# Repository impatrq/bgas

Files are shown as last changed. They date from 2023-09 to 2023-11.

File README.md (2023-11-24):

# BGas
Repositorio del proyecto BGas

## Integrantes:
- Britez, Franco  [codeSTACKr | LinkedIn][linkedinbr]

- Caceres, Luca  [codeSTACKr | LinkedIn][linkedinca]

- Chioli, Lautaro  [codeSTACKr | LinkedIn][linkedinch]

- Daglio, Santiago  [codeSTACKr | LinkedIn][linkedinda]

- Ferman, Joaquin  [codeSTACKr | LinkedIn][linkedinfe]

- Grochovski, Victor  [codeSTACKr | LinkedIn][linkedingr]

- Rossetti, Gonzalo  [codeSTACKr | LinkedIn][linkedinro] <br><br/>
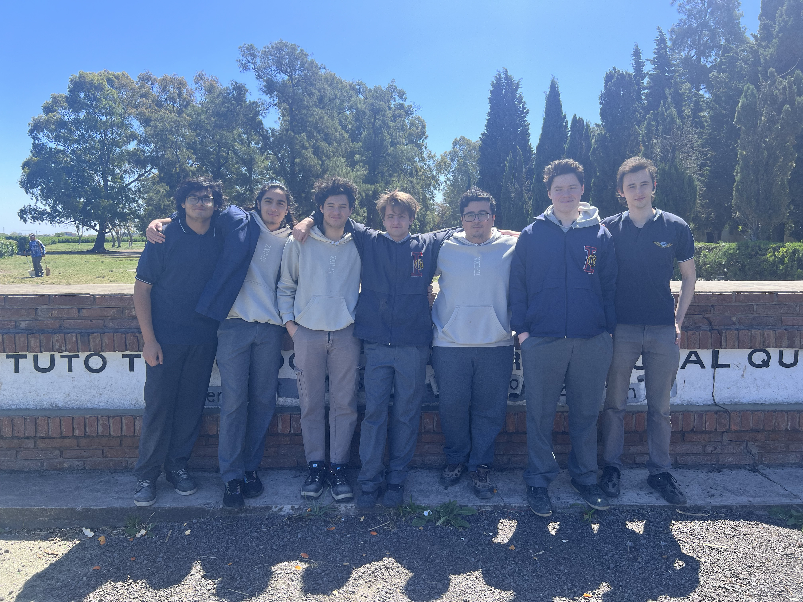
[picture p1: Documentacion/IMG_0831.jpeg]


## Objetivo:
BGas es un sistema compuesto por un generador de biogas y un subsistema electronico de monitoreo para leer los parametros en tiempo real del proceso mencionado, y asi tener una generacion de energia mas facil y segura.

## ¿Que es el biogas?
El biogas es un gas natural producido por la descomposicion anaerobica de materia organica. Este gas esta compuesto entre un 60% y 70% de metano, siendo el resto principalmente dioxido de carbono. El biogas y el biometano (que se obtiene luego de que el biogas pase por un proceso de filtrado para que solo quede el metano) son las dos formas de bioenergia de mas rapido crecimiento a nivel mundial y se espera que tengan un rol clave en la transicion hacia un mundo mas sostenible.

## Funcionamiento 
Los residuos organicos deben ser colocados en el recipiente de biogas donde se someterán a un proceso de descomposicion anaerobica. Se podrá ver el proceso de produccion de biogas mediante un LCD 16x2 controlado por tres botones, o a traves de una aplicacion para telefonos celulares. Al final del proceso, el usuario obtendrá biogas y biofertilizante.  

## ¿Donde utilizarlo?
Si bien a un biodigestor se le puede sacar el maximo provecho en un establecimiento agropecuario o agroindustrial, incluso una casa en un area urbana puede crear una cantidad considerable de biogas. Nuestro sistema apunta a que cualquier establecimiento (ya sea rural o urbano) pueda generar energia de la forma mas eficiente posible. 

## Files tree

- main
  - App
    - android.txt
    - bin
    - buildozer.spec
    - main.kv
    - main.py
  - Documentacion
    - Carpetas
    - Certificados
    - Banner
    - Presentacion
    - BOM (Bill Of Material)
    - Manual de usuario
  - Electronica
    - Circuitos
    - PCBs
  - Estructura
    - Visuales de la estructura
  - Modelos
    - Modelos de blender
  - Programa principal
    - main.py
    - librerias
  - Web
    - CNAME
    - CSS
    - index.html
    - JS
  - Imagenes
    - Stickers
    - Logo

## Seguinos en nuestras redes:
[codeSTACKr | Instagram][instagram]
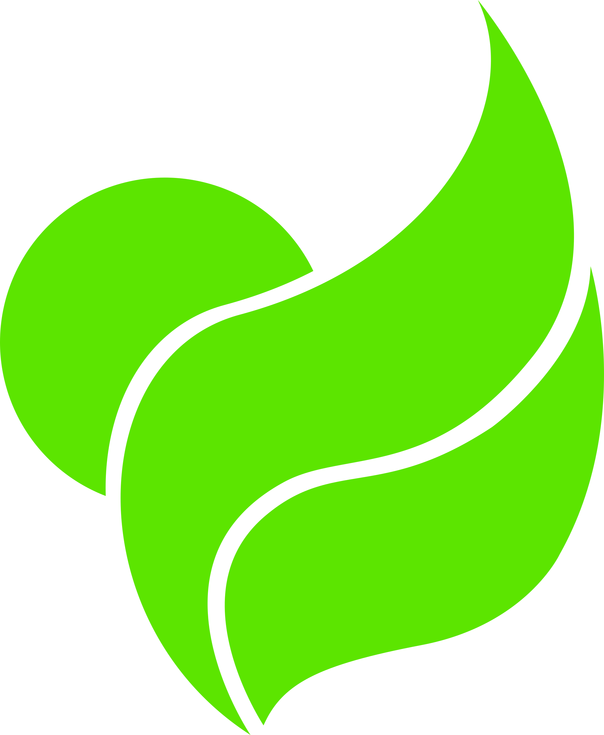
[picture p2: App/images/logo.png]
[][bgas]
[codeSTACKr | LinkedIn][linkedin]

[instagram]: https://instagram.com/proyecto.bgas?igshid=NGVhN2U2NjQ0Yg==
[bgas]: https://bgas.ar/
[Linkedin]: https://www.linkedin.com/company/101246268
[linkedinbr]: https://www.linkedin.com/in/franco-britez-b33523277/
[linkedinca]: https://www.linkedin.com/in/luca-c%C3%A1ceres-996389281/
[linkedinch]: https://www.linkedin.com/in/lautaro-chioli-87a68a27a/
[linkedinda]: https://www.linkedin.com/in/santiago-daglio-96b716295/
[linkedinfe]: https://www.linkedin.com/in/joaquin-ferman-b8b843259/
[linkedingr]: https://www.linkedin.com/in/victorgrochovski/
[linkedinro]: https://www.linkedin.com/in/gonzalo-rossetti-146219288/

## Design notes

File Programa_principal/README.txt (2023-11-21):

Carpeta para la programacion del micro.

Main.py ---->   Codigo principal del ESP32 transmisor

librerias:

LCD:       -lcd.api.py
           -i2c.lcd.py

MQ2:       -MQ2-py
           -BaseMQ.py

DS18B20:   -ds18x20.py
           -onewire.py

Otros:     -pyRTOS.py

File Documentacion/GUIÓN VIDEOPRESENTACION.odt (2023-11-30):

Bgas es un biodigestor inteligente, esta analizado por 3 sensores: mq2 sensor de gas, mpx5999d sensor de presión, ds18d20 sensor de temperatura. Esto es especialmente útil para los campos, dado la cantidad de abono que se puede usar para el biodigestor, además de las complicaciones que puede presentar para alguien que vive en el campo, considerando también las dificultades para obtener gas y lo costoso que puede resultar.

Al momento en que llega tu bgas, cargas el biodigestor con el mismo volumen de agua y materia orgánica; el volumen total puede ser de máximo 4/5 del balde (2/5 de agua y 2/5 de materia orgánica). En un plazo de 14 días, inicia la producción de tu propio gas.

La materia orgánica estará generando gas durante 4 meses; después de ese período, es necesario cambiar el contenido. La cantidad de gas generado dependerá del tipo de materia que pongas en el bgas.

Es necesario comprar otro biodigestor si el primero está dañado. Los materiales utilizados para un bgas están compuestos de plástico y metal. Sin embargo, si se trata de forma adecuada, el biodigestor puede durar toda tu vida.

El gas generado puede ser utilizado para cocina, calefacción y cualquier necesidad hogareña. Si tienes una buena cantidad de gas generado mensualmente, no será necesario volver a pagar por el servicio de gas.

El biodigestor es alimentado por energía solar, ya que no se necesita mucha energía para que todo funcione con normalidad.

Existen dos formas de revisar la información del biodigestor: puedes verla en la pantalla que se encuentra en el mismo, y también puedes descargar nuestra aplicación que proporciona esa información e informa del pico de eficiencia del biogás y cuánto tiempo durará dicho pico de eficiencia.

La application se comunica con el biodigestor atrabes de una antena de cumunicacion por internet llamada LORA

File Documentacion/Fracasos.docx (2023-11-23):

Fracasos

LoRa:

Documentación Usada:

https://github.com/rpsreal/pySX127x/blob/master/

Una de las librerías con las que más lejos llegue, no hubo problemas de compatibilidad con el micro usado, tampoco con el lenguaje, pero cuando intente usar el código de prueba con la librería ofrecida, me daba errores relacionados a la propia librería, y al estar relacionados a protocolos I2C, tema en el cual no estoy tan capacitado como para solucionar algo así, pase a la siguiente (Aunque en retrospectiva era la que tenia más chance de funcionar).

https://www.instructables.com/Arduino-LoRa-ESP32-LoRa-Gateway-Obtain-Remote-Ardu/

Confundido al principio por la diferencia, este ofrece un codigo para un módulo LoRaWAN, muy similar pero igualmente tuve problemas al momento de declarar los pines de mi módulo comparados con el del “tutorial”.

https://github.com/lemariva/uPyLoRaWAN/blob/master/main.py

Con diferencia con el que más lejos llegué, resolví algunos problemas (por ejemplo bypasee una autenticación de versión de python atrasada), pero al momento de hacerlo andar, lo cual ocurrió sin problemas, simplemente no hizo nada. Más específicamente el ESP encargado de enviar información informaba hacerlo, el encargado de recibirla lo mismo, pero algo en el medio no andaba. Dada la naturaleza del problema, que iba de la mano de un error en la comunicación (I2C) y no uno de lógica, decidí pasar a la siguiente librería.

https://www.arduino.cc/reference/en/libraries/lora/

Adicionalmente, intente usar una librería de arduino (lenguaje del cual es nativo el módulo) aunque no tuve disponible un módulo arduino a la mano en el poco tiempo hasta que un accidente rompió la antena de uno de los módulos, así incapacitando mis posibilidades de probar la comunicación aunque sea de esta forma tan precaria.

https://lemariva.com/blog/2020/02/tutorial-micropython-esp32-sends-data-over-lorawan

Use muy poco tiempo lo ofrecido por esta pagina, dado a que se me hizo tediosa la forma que tenía de explicar las cosas. Interrumpir su uso solo porque encontré la última a mencionar.

https://github.com/Inteform/PyLora

La última librería que llegue a intentar usar, cerca del viaje a las ONIET. En principio estaba emocionado por usarla (se llama literalmente PyLora) pero por razones que no termino de entender, está en lenguaje C. Igualmente, un archivo llamado setup.py parece poder usar librerías en C.

Una vez que volvimos hasta que llegó la feria no tuvimos el módulo con la antena rota reparada, y para cuando lo estuvo, el módulo sano desapareció. No estoy nada orgulloso de lo que pasó, considerando que el mismo tuvo absolutamente 0 uso en ese tiempo, así que lo atribuyó a un hurto, considerando que guardabamos esa (entre otras cosas) dentro del gabinete que formaba parte del proyecto.

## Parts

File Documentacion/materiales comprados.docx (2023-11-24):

Lista de materiales comprados:

Placas de cobre 10x10

2 esp 32 wroom

2 módulos LoRa

3 botones LED

sensor de temperatura ds18b20

sensor de presión MPX5999D

sensor de gas metano MQ2

LCD i2c 16x2

Cable DB9 x 1.8m

tacho 40l

el resto de materiales o componentes fueron reciclados.

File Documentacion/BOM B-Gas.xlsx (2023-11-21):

BOM Level | Nombre | Fabricante | cantidad | Precio un. | Precio | Total | Enlace
1 | ESP32 | nomdecu | 2 | 10 | 20
2 | LoRa | duaitek | 2 | 10 | 20
3 | Balde Her | sanimar | 1 | 2 | 2
4 | DS18B20 | todomicro | 1 | 1.8 | 1.8
5 | mq2 | duaitek | 1 | 2 | 2
6 | mx5999d | motorola | 1 | 24 | 24
7 | lcd 16x2 | duaitek | 1 | 4 | 4
8 | llave de gas | ciagas | 1 | 8 | 8
9 | botones | generico | 3 | 1.3 | 3.9
10 | desgue | aqua system | 1 | 6.3 | 6.3
11 | cable db9 | sf cable | 1 | 5 | 5
12 | placas |  | 3 | 10 | 30
13 | bisagra | fch | 2 | 1.1 | 2.2
14 | cerrojo | metagro srl | 1 | 2.2 | 2.2
15 | panel solar | solartec | 1 | 29 | 29
16 | bateria | kaise | 1 | 16 | 16
17 | archivero |  | 1 | 40 | 40
 |  |  |  |  |  | 216.4
 |  |  |  |  |  | 200.170 pe

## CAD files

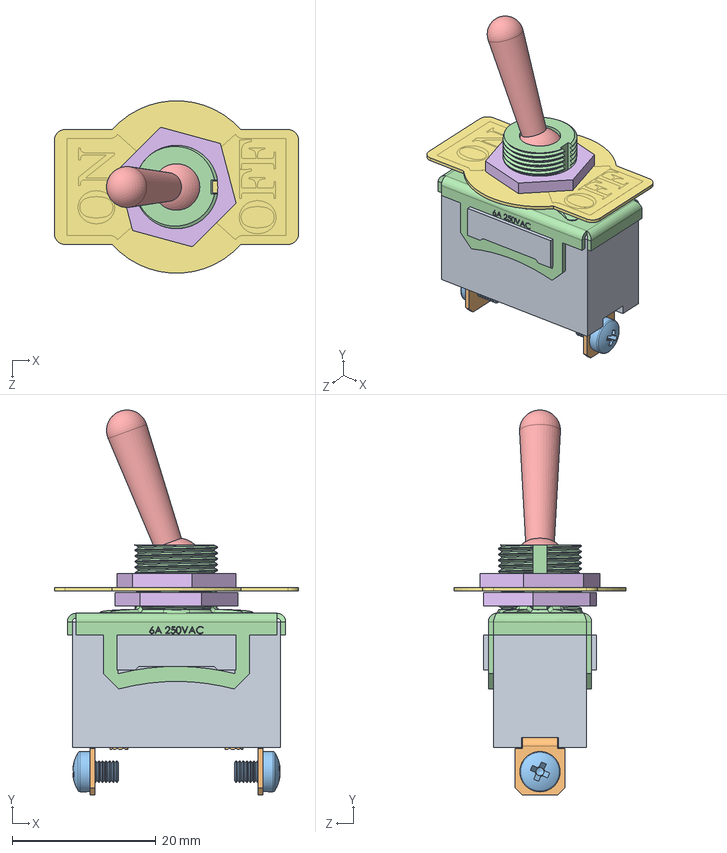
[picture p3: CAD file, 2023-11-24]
Electronica/prototipos no usados y desarrollo/tercera placa bgas (funcional)/componentes/switch/Toggle Switch.SLDASM
34.0 x 53.6 x 23.9 mm
Power jack x 2
pan head cross recess screw_iso M3-4 x 2
Cover
Handle
Nut x 2
Lable Plate

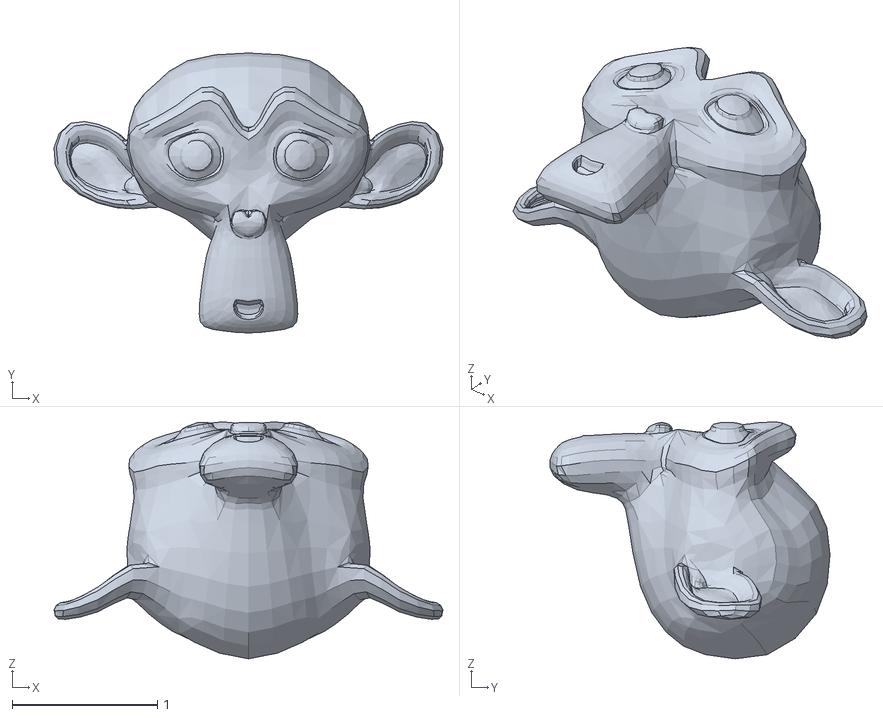
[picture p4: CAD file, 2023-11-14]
App/.buildozer/android/app/kivy_venv/share/kivy-examples/3Drendering/monkey.obj
2.67 x 1.92 x 1.63

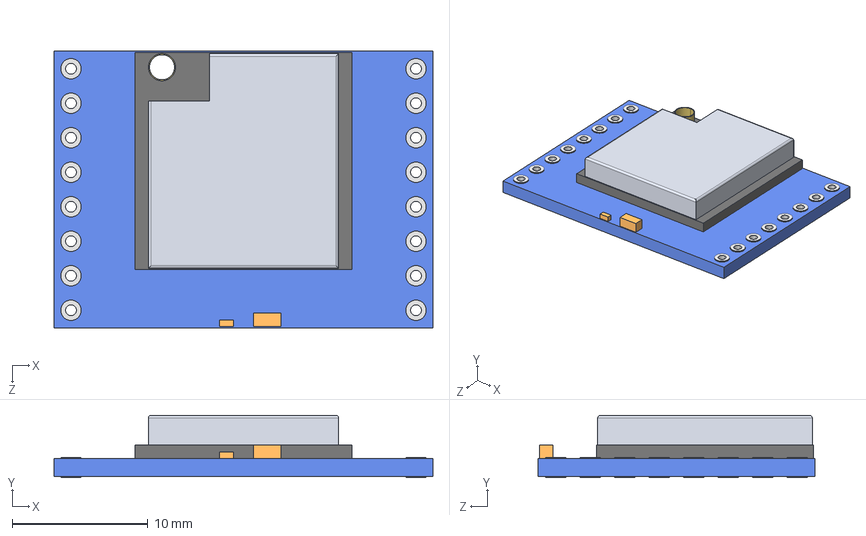
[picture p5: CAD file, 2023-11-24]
Electronica/componenentes/Lora/lora-ra-02-ai-thinker.STEP
27.9 x 4.60 x 20.4 mm

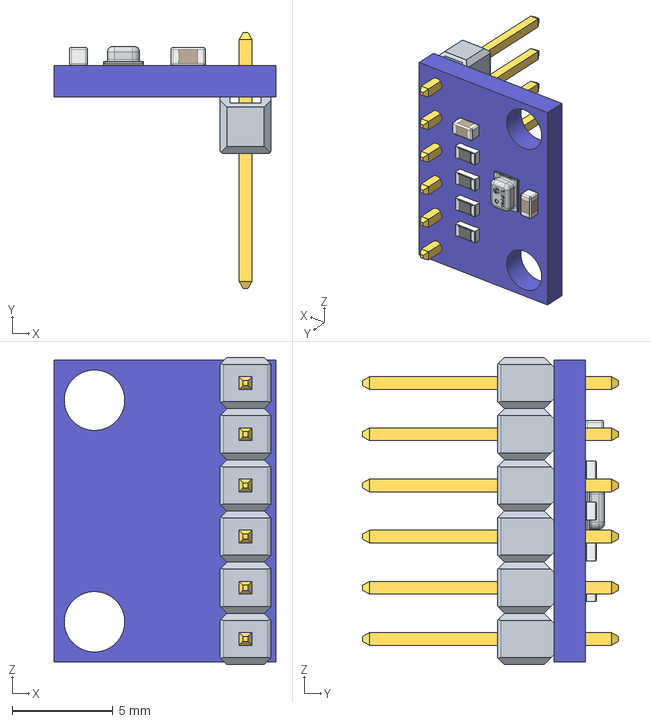
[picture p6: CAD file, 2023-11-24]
Electronica/prototipos no usados y desarrollo/tercera placa bgas (funcional)/componentes/BMP280/bmp280_module.stp
11.0 x 12.7 x 15.2 mm

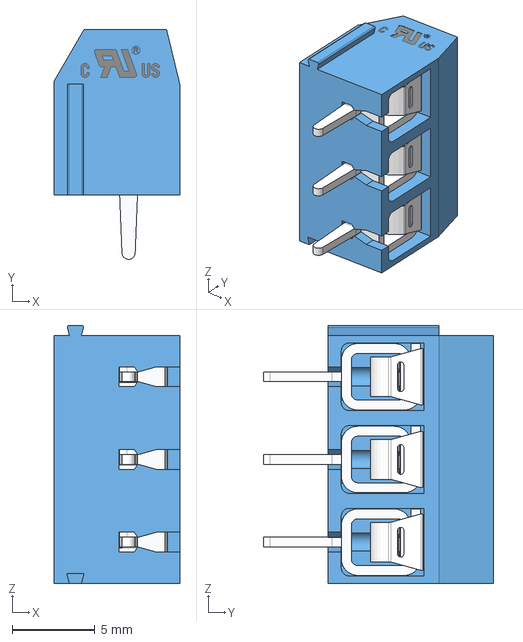
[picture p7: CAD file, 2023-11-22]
Electronica/prototipos no usados y desarrollo/tercera placa bgas (funcional)/componentes/DG306-SERIE 5 (2-14 PIN)/3 PIN DG306-5 BLUE - PITCH 5 mm.stp
7.60 x 13.9 x 15.6 mm

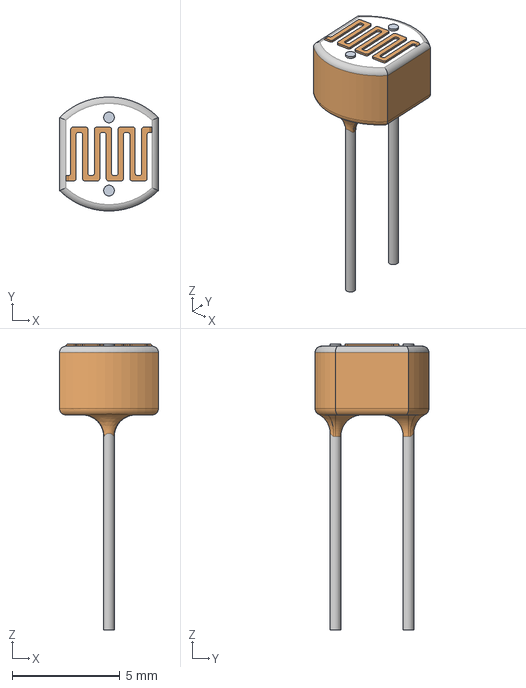
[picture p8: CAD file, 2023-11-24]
Electronica/prototipos no usados y desarrollo/tercera placa bgas (funcional)/componentes/LDR/Ldr.step
4.60 x 5.30 x 13.3 mm

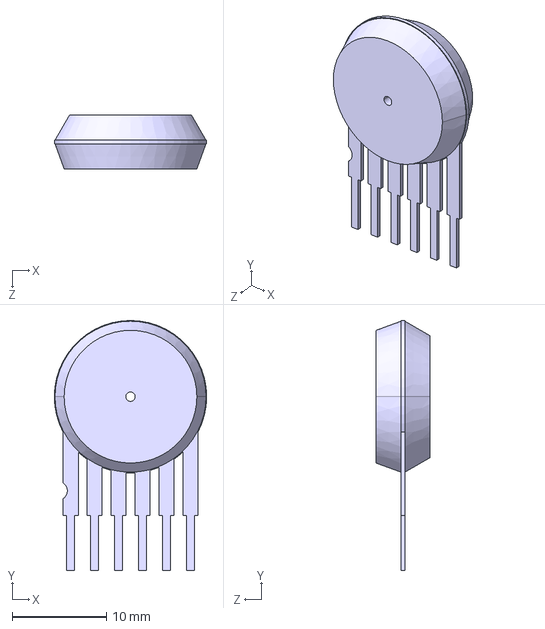
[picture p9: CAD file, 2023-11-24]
Electronica/prototipos no usados y desarrollo/tercera placa bgas (funcional)/componentes/MPX5999D 2/User Library-MPX5999D.STEP
16.1 x 26.5 x 5.72 mm

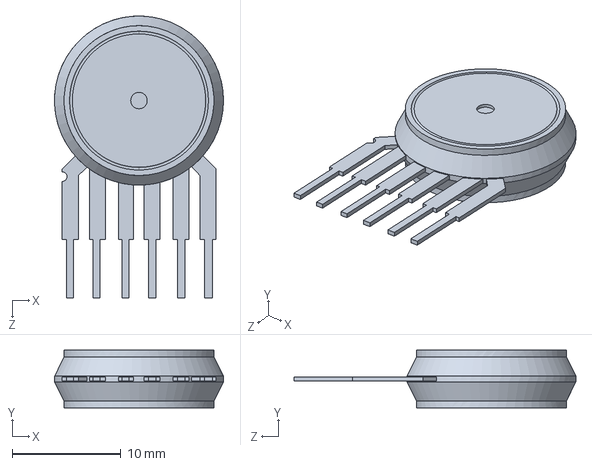
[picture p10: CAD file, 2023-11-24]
Electronica/prototipos no usados y desarrollo/tercera placa bgas (funcional)/componentes/MPX5999D/MPX5999D.SLDPRT
15.6 x 5.33 x 25.9 mm

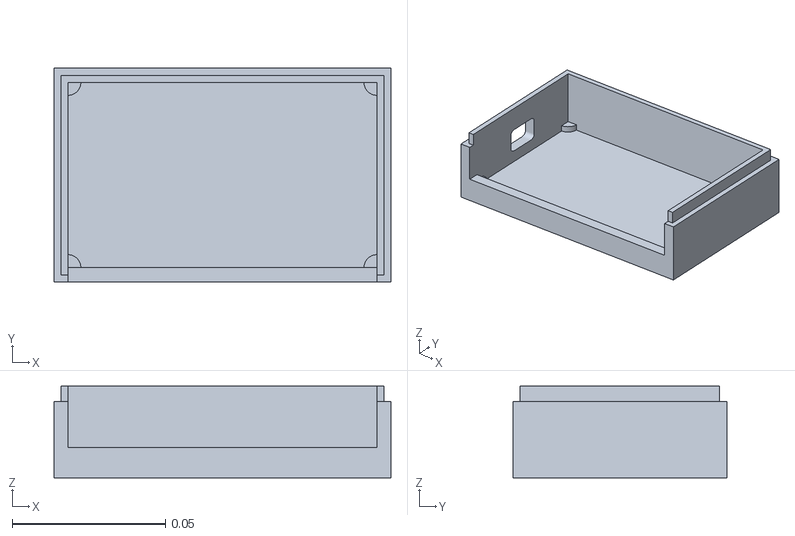
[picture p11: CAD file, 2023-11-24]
Modelos/Transmisor_BOT_Print.stl
0.11 x 0.07 x 0.03

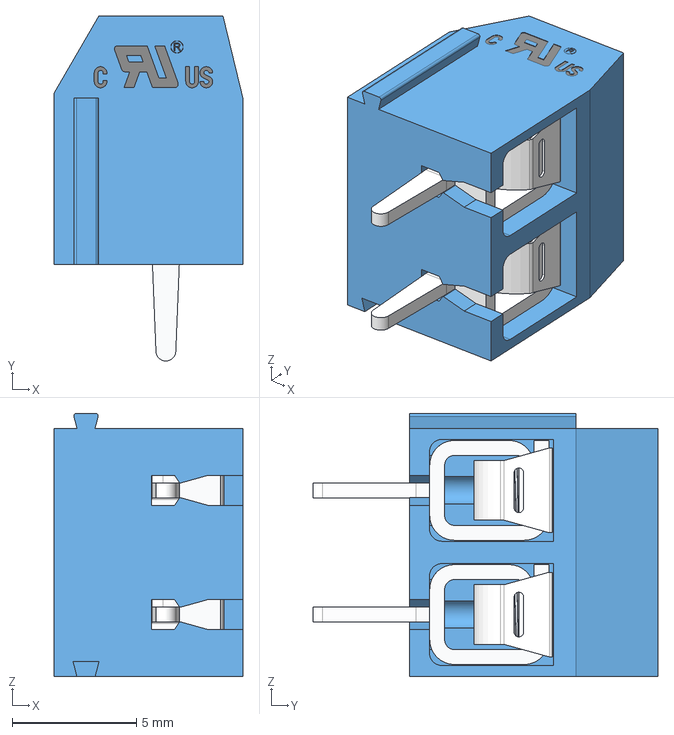
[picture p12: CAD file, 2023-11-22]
Electronica/prototipos no usados y desarrollo/tercera placa bgas (funcional)/componentes/DG306-SERIE 5 (2-14 PIN)/2 PIN DG306-5 BLUE - PITCH 5 mm.stp
7.60 x 13.9 x 10.6 mm

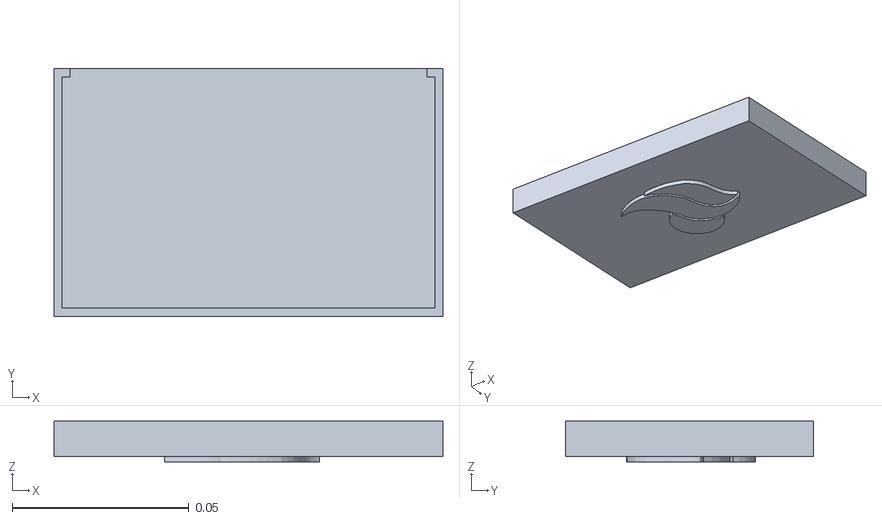
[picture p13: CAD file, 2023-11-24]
Modelos/Transmisor_TOP_Printer.stl
0.11 x 0.07 x 0.0116

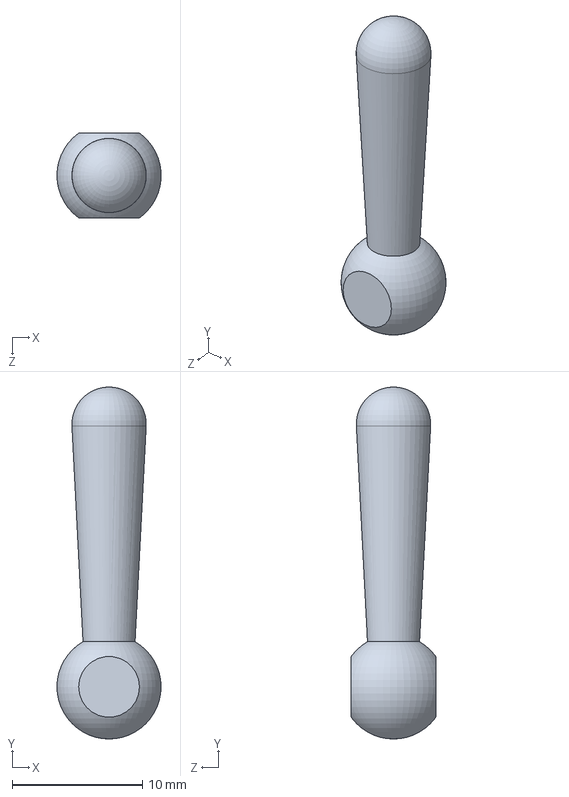
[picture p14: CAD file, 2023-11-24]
Electronica/prototipos no usados y desarrollo/tercera placa bgas (funcional)/componentes/switch/Handle.SLDPRT
7.99 x 27.0 x 6.50 mm

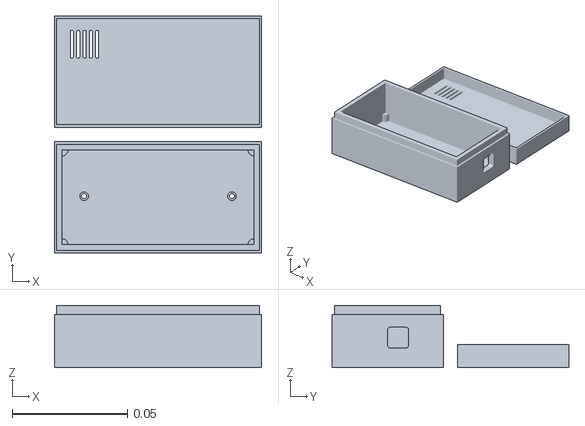
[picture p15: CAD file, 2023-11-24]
Modelos/Reciver_Print.stl
0.0902 x 0.103 x 0.027

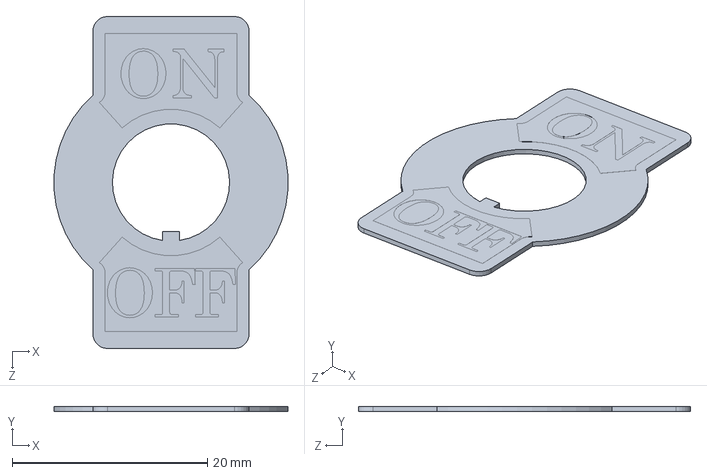
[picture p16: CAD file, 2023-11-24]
Electronica/prototipos no usados y desarrollo/tercera placa bgas (funcional)/componentes/switch/Lable Plate.SLDPRT
23.9 x 0.51 x 34.0 mm

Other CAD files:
App/.buildozer/android/platform/build-arm64-v8a_armeabi-v7a/build/other_builds/kivy/arm64-v8a__ndk_target_21/kivy/examples/3Drendering/monkey.obj
App/.buildozer/android/platform/build-arm64-v8a_armeabi-v7a/build/other_builds/kivy/armeabi-v7a__ndk_target_21/kivy/examples/3Drendering/monkey.obj
Electronica/prototipos no usados y desarrollo/tercera placa bgas (funcional)/componentes/switch/Cover.SLDPRT
Electronica/prototipos no usados y desarrollo/tercera placa bgas (funcional)/componentes/switch/Power jack.SLDPRT
Documentacion/bmp280_module_Shrinkwrap.ipt
Electronica/prototipos no usados y desarrollo/tercera placa bgas (funcional)/componentes/MPX5999D/MPX5999D.IGS
Electronica/prototipos no usados y desarrollo/tercera placa bgas (funcional)/componentes/switch/Body.SLDPRT
Electronica/prototipos no usados y desarrollo/tercera placa bgas (funcional)/componentes/switch/Nut.SLDPRT
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

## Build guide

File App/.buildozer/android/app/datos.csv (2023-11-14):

2023/10/16 19:15:22 | quilmes | 0
2023/10/16 19:15:33 | Quilmes | 0
2023/10/16 19:19:16 | quilmes | 0

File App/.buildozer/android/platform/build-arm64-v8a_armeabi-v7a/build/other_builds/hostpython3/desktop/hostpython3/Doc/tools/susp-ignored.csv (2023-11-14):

c-api/arg |  | :ref | PyArg_ParseTuple(args, "O|O:ref", &object, &callback)
c-api/list |  | :high | list[low:high]
c-api/sequence |  | :i2 | del o[i1:i2]
c-api/sequence |  | :i2 | o[i1:i2]
c-api/tuple |  | :high | p[low:high]
c-api/unicode |  | :end | str[start:end]
c-api/unicode |  | :start | unicode[start:start+length]
distutils/examples |  | ` | This is the description of the ``foobar`` package.
distutils/setupscript |  | ::
extending/embedding |  | :numargs | if(!PyArg_ParseTuple(args, ":numargs"))
extending/extending |  | :myfunction | PyArg_ParseTuple(args, "D:myfunction", &c);
extending/extending |  | :set | if (PyArg_ParseTuple(args, "O:set_callback", &temp)) {
extending/newtypes |  | :call | if (!PyArg_ParseTuple(args, "sss:call", &arg1, &arg2, &arg3)) {
faq/programming |  | :chr | >=4.0) or 1+f(xc,yc,x*x-y*y+xc,2.0*x*y+yc,k-1,f):f(xc,yc,x,y,k,f):chr(
faq/programming |  | :reduce | print((lambda Ru,Ro,Iu,Io,IM,Sx,Sy:reduce(lambda x,y:x+'\n'+y,map(lambda y,
faq/programming |  | :reduce | Sx=Sx,Sy=Sy:reduce(lambda x,y:x+y,map(lambda x,xc=Ru,yc=yc,Ru=Ru,Ro=Ro,
faq/windows |  | :d48eceb | Python 3.6.4 (v3.6.4:d48eceb, Dec 19 2017, 06:04:45) [MSC v.1900 32 bit (Intel)] on win32
howto/curses |  | :black | colors when it activates color mode. They are: 0:black, 1:red,
howto/curses |  | :red | colors when it activates color mode. They are: 0:black, 1:red,
howto/curses |  | :green | 2:green, 3:yellow, 4:blue, 5:magenta, 6:cyan, and 7:white. The
howto/curses |  | :yellow | 2:green, 3:yellow, 4:blue, 5:magenta, 6:cyan, and 7:white. The
howto/curses |  | :blue | 2:green, 3:yellow, 4:blue, 5:magenta, 6:cyan, and 7:white. The
howto/curses |  | :magenta | 2:green, 3:yellow, 4:blue, 5:magenta, 6:cyan, and 7:white. The
howto/curses |  | :cyan | 2:green, 3:yellow, 4:blue, 5:magenta, 6:cyan, and 7:white. The
howto/curses |  | :white | 2:green, 3:yellow, 4:blue, 5:magenta, 6:cyan, and 7:white. The
howto/descriptor |  | :root | INFO:root
howto/descriptor |  | :Updating | root:Updating
howto/descriptor |  | :Accessing | root:Accessing
howto/instrumentation |  | :: | python$target:::function-entry
howto/instrumentation |  | :function | python$target:::function-entry
howto/instrumentation |  | :: | python$target:::function-return
howto/instrumentation |  | :function | python$target:::function-return
howto/instrumentation |  | :call | 156641360502280 function-entry:call_stack.py:start:23
howto/instrumentation |  | :start | 156641360502280 function-entry:call_stack.py:start:23
howto/instrumentation |  | :function | 156641360518804 function-entry: call_stack.py:function_1:1
howto/instrumentation |  | :function | 156641360532797 function-entry: call_stack.py:function_3:9
howto/instrumentation |  | :function | 156641360546807 function-return: call_stack.py:function_3:10
howto/instrumentation |  | :function | 156641360563367 function-return: call_stack.py:function_1:2
howto/instrumentation |  | :function | 156641360578365 function-entry: call_stack.py:function_2:5
howto/instrumentation |  | :function | 156641360591757 function-entry: call_stack.py:function_1:1
howto/instrumentation |  | :function | 156641360605556 function-entry: call_stack.py:function_3:9
howto/instrumentation |  | :function | 156641360617482 function-return: call_stack.py:function_3:10
howto/instrumentation |  | :function | 156641360629814 function-return: call_stack.py:function_1:2
howto/instrumentation |  | :function | 156641360642285 function-return: call_stack.py:function_2:6
howto/instrumentation |  | :function | 156641360656770 function-entry: call_stack.py:function_3:9
howto/instrumentation |  | :function | 156641360669707 function-return: call_stack.py:function_3:10
howto/instrumentation |  | :function | 156641360687853 function-entry: call_stack.py:function_4:13
howto/instrumentation |  | :function | 156641360700719 function-return: call_stack.py:function_4:14
howto/instrumentation |  | :function | 156641360719640 function-entry: call_stack.py:function_5:18
howto/instrumentation |  | :function | 156641360732567 function-return: call_stack.py:function_5:21
howto/instrumentation |  | :call | 156641360747370 function-return:call_stack.py:start:28
howto/instrumentation |  | :start | 156641360747370 function-return:call_stack.py:start:28
howto/ipaddress |  | :DB8 | >>> ipaddress.ip_address('2001:DB8::1')
howto/ipaddress |  | :: | >>> ipaddress.ip_address('2001:DB8::1')
howto/ipaddress |  | :db8 | IPv6Address('2001:db8::1')
howto/ipaddress |  | :: | IPv6Address('2001:db8::1')
howto/ipaddress |  | :: | IPv6Address('::1')
howto/ipaddress |  | :db8 | >>> ipaddress.ip_network('2001:db8::0/96')
howto/ipaddress |  | :: | >>> ipaddress.ip_network('2001:db8::0/96')
howto/ipaddress |  | :db8 | IPv6Network('2001:db8::/96')
howto/ipaddress |  | :: | IPv6Network('2001:db8::/96')
howto/ipaddress |  | :db8 | IPv6Network('2001:db8::/128')
howto/ipaddress |  | :: | IPv6Network('2001:db8::/128')
howto/ipaddress |  | :db8 | IPv6Interface('2001:db8::1/96')
howto/ipaddress |  | :: | IPv6Interface('2001:db8::1/96')
howto/ipaddress |  | :db8 | >>> addr6 = ipaddress.ip_address('2001:db8::1')
howto/ipaddress |  | :: | >>> addr6 = ipaddress.ip_address('2001:db8::1')
howto/ipaddress |  | :db8 | >>> host6 = ipaddress.ip_interface('2001:db8::1/96')
howto/ipaddress |  | :: | >>> host6 = ipaddress.ip_interface('2001:db8::1/96')
howto/ipaddress |  | :db8 | >>> net6 = ipaddress.ip_network('2001:db8::0/96')
howto/ipaddress |  | :: | >>> net6 = ipaddress.ip_network('2001:db8::0/96')
howto/ipaddress |  | :ffff | IPv6Address('ffff:ffff:ffff:ffff:ffff:ffff::')
howto/ipaddress |  | :: | IPv6Address('ffff:ffff:ffff:ffff:ffff:ffff::')
howto/ipaddress |  | :: | IPv6Address('::ffff:ffff')
howto/ipaddress |  | :ffff | IPv6Address('::ffff:ffff')
howto/ipaddress |  | :db8 | '2001:db8::/96'
howto/ipaddress |  | :: | '2001:db8::/96'
howto/ipaddress |  | :db8 | >>> ipaddress.ip_interface('2001:db8::1/96')
howto/ipaddress |  | :: | >>> ipaddress.ip_interface('2001:db8::1/96')
howto/ipaddress |  | :db8 | '2001:db8::1'
howto/ipaddress |  | :: | '2001:db8::1'
howto/ipaddress |  | :db8 | IPv6Address('2001:db8::ffff:ffff')
howto/ipaddress |  | :: | IPv6Address('2001:db8::ffff:ffff')
howto/ipaddress |  | :ffff | IPv6Address('2001:db8::ffff:ffff')
howto/logging |  | :And | WARNING:And this, too
howto/logging |  | :And | WARNING:root:And this, too
howto/logging |  | :And | ERROR:root:And non-ASCII stuff, too, like
howto/logging |  | :Doing | INFO:root:Doing something
howto/logging |  | :Finished | INFO:root:Finished
howto/logging |  | :logger | severity:logger name:message
howto/logging |  | :Look | WARNING:root:Look before you leap!
howto/logging |  | :message | severity:logger name:message
howto/logging |  | :root | DEBUG:root:This message should go to the log file
howto/logging |  | :root | INFO:root:Doing something
howto/logging |  | :root | INFO:root:Finished
howto/logging |  | :root | INFO:root:So should this
howto/logging |  | :root | ERROR:root:And non-ASCII stuff, too, like
howto/logging |  | :root | INFO:root:Started
howto/logging |  | :root | WARNING:root:And this, too
howto/logging |  | :root | WARNING:root:Look before you leap!
howto/logging |  | :root | WARNING:root:Watch out!
howto/logging |  | :So | INFO:root:So should this
howto/logging |  | :So | INFO:So should this
howto/logging |  | :Started | INFO:root:Started
howto/logging |  | :This | DEBUG:root:This message should go to the log file
howto/logging |  | :This | DEBUG:This message should appear on the console
howto/logging |  | :Watch | WARNING:root:Watch out!
howto/pyporting |  | :: | Programming Language :: Python :: 2
howto/pyporting |  | :: | Programming Language :: Python :: 3
howto/regex |  | ::
howto/regex |  | :foo | (?:foo)
howto/urllib2 |  | :password | "joe:password@example.com"
library/__main__ |  | `
library/ast |  | :upper | lower:upper
library/ast |  | :step | lower:upper:step
library/audioop |  | :ipos | # factor = audioop.findfactor(in_test[ipos*2:ipos*2+len(out_test)],
library/configparser |  | :home | my_dir: ${Common:home_dir}/twosheds
library/configparser |  | :option | ${section:option}
library/configparser |  | :path | python_dir: ${Frameworks:path}/Python/Versions/${Frameworks:Python}
library/configparser |  | :Python | python_dir: ${Frameworks:path}/Python/Versions/${Frameworks:Python}
library/configparser |  | :system | path: ${Common:system_dir}/Library/Frameworks/
library/datetime |  | :MM
library/datetime |  | :SS
library/decimal |  | :optional | trailneg:optional trailing minus indicator
library/difflib |  | :ahi | a[alo:ahi]
library/difflib |  | :bhi | b[blo:bhi]
library/difflib |  | :i1
library/difflib |  | :i2
library/difflib |  | :j2
library/doctest |  | ` | ``factorial`` from the ``example`` module:
library/doctest |  | ` | The ``example`` module
library/doctest |  | ` | Using ``factorial``
library/exceptions |  | :err | err.object[err.start:err.end]
library/functions |  | :step | a[start:stop:step]
library/functions |  | :stop | a[start:stop, i]
library/functions |  | :stop | a[start:stop:step]
library/hashlib |  | :LEAF | h00 = blake2b(buf[0:LEAF_SIZE], fanout=FANOUT, depth=DEPTH,
library/http.client |  | :port | host:port
library/http.cookies |  | ` | !#$%&'*+-.^_`|~:
library/imaplib |  | :MM | "DD-Mmm-YYYY HH:MM:SS
library/imaplib |  | :SS | "DD-Mmm-YYYY HH:MM:SS
library/inspect |  | :int | >>> def foo(a, *, b:int, **kwargs):
library/inspect |  | :int | '(a, *, b:int, **kwargs)'
library/inspect |  | :int | 'b:int'
library/ipaddress |  | :db8 | >>> ipaddress.ip_address('2001:db8::')
library/ipaddress |  | :: | >>> ipaddress.ip_address('2001:db8::')
library/ipaddress |  | :db8 | IPv6Address('2001:db8::')
library/ipaddress |  | :: | IPv6Address('2001:db8::')
library/ipaddress |  | :db8 | >>> ipaddress.IPv6Address('2001:db8::1000')
library/ipaddress |  | :: | >>> ipaddress.IPv6Address('2001:db8::1000')
library/ipaddress |  | :db8 | '2001:db8::1000'
library/ipaddress |  | :: | '2001:db8::1000'
library/ipaddress |  | :db8 | >>> f'{ipaddress.IPv6Address("2001:db8::1000"):s}'
library/ipaddress |  | :: | >>> f'{ipaddress.IPv6Address("2001:db8::1000"):s}'
library/ipaddress |  | :: | IPv6Address('ff02::5678%1')
library/ipaddress |  | :: | fe80::1234
library/ipaddress |  | :db8 | >>> ipaddress.ip_address("2001:db8::1").reverse_pointer
library/ipaddress |  | :: | >>> ipaddress.ip_address("2001:db8::1").reverse_pointer
library/ipaddress |  | :: | "::abc:7:def"
library/ipaddress |  | :def | "::abc:7:def"
library/ipaddress |  | :: | ::FFFF/96
library/ipaddress |  | :: | 2002::/16
library/ipaddress |  | :: | 2001::/32
library/ipaddress |  | :: | >>> str(ipaddress.IPv6Address('::1'))
library/ipaddress |  | :: | '::1'
library/ipaddress |  | :ff00 | ffff:ff00::
library/ipaddress |  | :db00 | 2001:db00::0/24
library/ipaddress |  | :: | 2001:db00::0/24
library/ipaddress |  | :db00 | 2001:db00::0/ffff:ff00::
library/ipaddress |  | :: | 2001:db00::0/ffff:ff00::
library/itertools |  | :step | elements from seq[start:stop:step]
library/itertools |  | :: | kernel = tuple(kernel)[::-1]
library/itertools |  | :stop | elements from seq[start:stop:step]
library/logging |  | :root | WARNING:root:Watch out!
library/logging |  | :Watch | WARNING:root:Watch out!
library/logging.handlers |  | :port | host:port
library/mmap |  | :i2 | obj[i1:i2]
library/multiprocessing |  | ` | # Add more tasks using `put()`
library/multiprocessing |  | :queue | >>> QueueManager.register('get_queue', callable=lambda:queue)
library/multiprocessing |  | ` | # register the Foo class; make `f()` and `g()` accessible via proxy
library/multiprocessing |  | ` | # register the Foo class; make `g()` and `_h()` accessible via proxy
library/multiprocessing |  | ` | # register the generator function baz; use `GeneratorProxy` to make proxies
library/nntplib |  | :bytes | :bytes
library/nntplib |  | :lines | :lines
library/optparse |  | :len | del parser.rargs[:len(value)]
library/os.path |  | :foo | c:foo
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

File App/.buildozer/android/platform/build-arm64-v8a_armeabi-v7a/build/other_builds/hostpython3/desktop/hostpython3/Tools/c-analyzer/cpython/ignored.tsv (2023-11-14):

filename | funcname | name | reason
#??? | - | somevar | ???
# XXX The analyzer should have ignored these (forward/extern references):
Include/py_curses.h | - | PyCurses_API | -
Include/pydecimal.h | - | _decimal_api | -
Modules/_blake2/blake2module.c | - | blake2b_type_spec | -
Modules/_blake2/blake2module.c | - | blake2s_type_spec | -
Modules/_io/fileio.c | - | _Py_open_cloexec_works | -
Modules/_io/_iomodule.h | - | PyIOBase_Type | -
Modules/_io/_iomodule.h | - | PyRawIOBase_Type | -
Modules/_io/_iomodule.h | - | PyBufferedIOBase_Type | -
Modules/_io/_iomodule.h | - | PyTextIOBase_Type | -
Modules/_io/_iomodule.h | - | PyFileIO_Type | -
Modules/_io/_iomodule.h | - | PyBytesIO_Type | -
Modules/_io/_iomodule.h | - | PyStringIO_Type | -
Modules/_io/_iomodule.h | - | PyBufferedReader_Type | -
Modules/_io/_iomodule.h | - | PyBufferedWriter_Type | -
Modules/_io/_iomodule.h | - | PyBufferedRWPair_Type | -
Modules/_io/_iomodule.h | - | PyBufferedRandom_Type | -
Modules/_io/_iomodule.h | - | PyTextIOWrapper_Type | -
Modules/_io/_iomodule.h | - | PyIncrementalNewlineDecoder_Type | -
Modules/_io/_iomodule.h | - | _PyBytesIOBuffer_Type | -
Modules/_io/_iomodule.h | - | _PyIO_str_close | -
Modules/_io/_iomodule.h | - | _PyIO_str_closed | -
Modules/_io/_iomodule.h | - | _PyIO_str_decode | -
Modules/_io/_iomodule.h | - | _PyIO_str_encode | -
Modules/_io/_iomodule.h | - | _PyIO_str_fileno | -
Modules/_io/_iomodule.h | - | _PyIO_str_flush | -
Modules/_io/_iomodule.h | - | _PyIO_str_getstate | -
Modules/_io/_iomodule.h | - | _PyIO_str_isatty | -
Modules/_io/_iomodule.h | - | _PyIO_str_newlines | -
Modules/_io/_iomodule.h | - | _PyIO_str_nl | -
Modules/_io/_iomodule.h | - | _PyIO_str_peek | -
Modules/_io/_iomodule.h | - | _PyIO_str_read | -
Modules/_io/_iomodule.h | - | _PyIO_str_read1 | -
Modules/_io/_iomodule.h | - | _PyIO_str_readable | -
Modules/_io/_iomodule.h | - | _PyIO_str_readall | -
Modules/_io/_iomodule.h | - | _PyIO_str_readinto | -
Modules/_io/_iomodule.h | - | _PyIO_str_readline | -
Modules/_io/_iomodule.h | - | _PyIO_str_reset | -
Modules/_io/_iomodule.h | - | _PyIO_str_seek | -
Modules/_io/_iomodule.h | - | _PyIO_str_seekable | -
Modules/_io/_iomodule.h | - | _PyIO_str_setstate | -
Modules/_io/_iomodule.h | - | _PyIO_str_tell | -
Modules/_io/_iomodule.h | - | _PyIO_str_truncate | -
Modules/_io/_iomodule.h | - | _PyIO_str_writable | -
Modules/_io/_iomodule.h | - | _PyIO_str_write | -
Modules/_io/_iomodule.h | - | _PyIO_empty_str | -
Modules/_io/_iomodule.h | - | _PyIO_empty_bytes | -
Modules/_multiprocessing/multiprocessing.h | - | _PyMp_SemLockType | -
Modules/_sqlite/cache.h | - | pysqlite_NodeType | -
Modules/_sqlite/cache.h | - | pysqlite_CacheType | -
Modules/_sqlite/cursor.h | - | pysqlite_CursorType | -
Modules/_sqlite/row.h | - | pysqlite_RowType | -
Modules/_sqlite/prepare_protocol.h | - | pysqlite_PrepareProtocolType | -
Modules/_sqlite/statement.h | - | pysqlite_StatementType | -
Modules/_sqlite/connection.h | - | pysqlite_ConnectionType | -
Modules/_sqlite/module.c | - | pysqlite_Error | -
Modules/_sqlite/module.c | - | pysqlite_Warning | -
Modules/_sqlite/module.c | - | pysqlite_InterfaceError | -
Modules/_sqlite/module.c | - | pysqlite_DatabaseError | -
Modules/_sqlite/module.c | - | pysqlite_InternalError | -
Modules/_sqlite/module.c | - | pysqlite_OperationalError | -
Modules/_sqlite/module.c | - | pysqlite_ProgrammingError | -
Modules/_sqlite/module.c | - | pysqlite_IntegrityError | -
Modules/_sqlite/module.c | - | pysqlite_DataError | -
Modules/_sqlite/module.c | - | pysqlite_NotSupportedError | -
Modules/_sqlite/module.c | - | _pysqlite_converters | -
Modules/_sqlite/module.c | - | _pysqlite_enable_callback_tracebacks | -
Modules/_sqlite/module.c | - | pysqlite_BaseTypeAdapted | -
Modules/_testcapimodule.c | - | _PyBytesIOBuffer_Type | -
Modules/posixmodule.c | - | _Py_open_cloexec_works | -
Python/importdl.h | - | _PyImport_DynLoadFiletab | -
##################################
# test code
# []
Modules/_ctypes/_ctypes_test.c | - | _ctypes_test_slots | -
Modules/_ctypes/_ctypes_test.c | - | module_methods | -
Modules/_ctypes/_ctypes_test.c | - | my_spams | -
Modules/_ctypes/_ctypes_test.c | - | my_eggs | -
Modules/_ctypes/_ctypes_test.c | - | an_integer | -
Modules/_ctypes/_ctypes_test.c | - | _xxx_lib | -
Modules/_ctypes/_ctypes_test.c | - | left | -
Modules/_ctypes/_ctypes_test.c | - | top | -
Modules/_ctypes/_ctypes_test.c | - | right | -
Modules/_ctypes/_ctypes_test.c | - | bottom | -
Modules/_ctypes/_ctypes_test.c | - | _ctypes_testmodule | -
Modules/_ctypes/_ctypes_test.c | - | last_tfrsuv_arg | -
Modules/_ctypes/_ctypes_test.c | - | last_tf_arg_s | -
Modules/_ctypes/_ctypes_test.c | - | last_tf_arg_u | -
Modules/_testbuffer.c | - | simple_format | -
Modules/_testbuffer.c | - | static_mem | -
Modules/_testbuffer.c | - | static_shape | -
Modules/_testbuffer.c | - | static_strides | -
Modules/_testbuffer.c | - | NDArray_Type | -
Modules/_testbuffer.c | - | StaticArray_Type | -
Modules/_testbuffer.c | ndarray_init | kwlist | -
Modules/_testbuffer.c | ndarray_push | kwlist | -
Modules/_testbuffer.c | staticarray_init | kwlist | -
Modules/_testbuffer.c | - | ndarray_methods | -
Modules/_testbuffer.c | - | _testbuffer_functions | -
Modules/_testbuffer.c | - | ndarray_getset | -
Modules/_testbuffer.c | - | ndarray_as_buffer | -
Modules/_testbuffer.c | - | staticarray_as_buffer | -
Modules/_testbuffer.c | - | ndarray_as_sequence | -
Modules/_testbuffer.c | - | ndarray_as_mapping | -
Modules/_testbuffer.c | - | structmodule | -
Modules/_testbuffer.c | - | _testbuffermodule | -
Modules/_testbuffer.c | - | Struct | -
Modules/_testbuffer.c | - | calcsize | -
Modules/_testbuffer.c | - | simple_fmt | -
Modules/_testbuffer.c | - | static_buffer | -
Modules/_testbuffer.c | ndarray_memoryview_from_buffer | format | -
Modules/_testbuffer.c | ndarray_memoryview_from_buffer | shape | -
Modules/_testbuffer.c | ndarray_memoryview_from_buffer | strides | -
Modules/_testbuffer.c | ndarray_memoryview_from_buffer | suboffsets | -
Modules/_testbuffer.c | ndarray_memoryview_from_buffer | info | -
Modules/_testbuffer.c | - | infobuf | -
Modules/_testcapimodule.c | - | TestError | -
Modules/_testcapimodule.c | test_capsule | buffer | -
Modules/_testcapimodule.c | - | decimal_initialized | -
Modules/_testcapimodule.c | - | thread_done | -
Modules/_testcapimodule.c | - | capsule_error | -
Modules/_testcapimodule.c | - | capsule_destructor_call_count | -
Modules/_testcapimodule.c | - | str1 | -
Modules/_testcapimodule.c | - | str2 | -
Modules/_testcapimodule.c | - | test_run_counter | -
Modules/_testcapimodule.c | - | FmHook | -
Modules/_testcapimodule.c | - | FmData | -
Modules/_testcapimodule.c | - | _testcapimodule | -
Modules/_testcapimodule.c | - | _HashInheritanceTester_Type | -
Modules/_testcapimodule.c | - | test_structmembersType | -
Modules/_testcapimodule.c | - | matmulType | -
Modules/_testcapimodule.c | - | ipowType | -
Modules/_testcapimodule.c | - | awaitType | -
Modules/_testcapimodule.c | - | PyRecursingInfinitelyError_Type | -
Modules/_testcapimodule.c | - | MyList_Type | -
Modules/_testcapimodule.c | - | GenericAlias_Type | -
Modules/_testcapimodule.c | - | Generic_Type | -
Modules/_testcapimodule.c | - | MethodDescriptorBase_Type | -
Modules/_testcapimodule.c | - | MethodDescriptorDerived_Type | -
Modules/_testcapimodule.c | - | MethodDescriptorNopGet_Type | -
Modules/_testcapimodule.c | - | MethodDescriptor2_Type | -
Modules/_testcapimodule.c | - | MethInstance_Type | -
Modules/_testcapimodule.c | - | MethClass_Type | -
Modules/_testcapimodule.c | - | MethStatic_Type | -
Modules/_testcapimodule.c | - | ContainerNoGC_type | -
Modules/_testcapimodule.c | slot_tp_del | PyId___tp_del__ | -
Modules/_testcapimodule.c | raise_SIGINT_then_send_None | PyId_send | -
Modules/_testcapimodule.c | - | HeapDocCType_spec | -
Modules/_testcapimodule.c | - | HeapGcCType_spec | -
Modules/_testcapimodule.c | - | HeapCType_spec | -
Modules/_testcapimodule.c | - | HeapCTypeSubclass_spec | -
Modules/_testcapimodule.c | - | HeapCTypeWithBuffer_spec | -
Modules/_testcapimodule.c | - | HeapCTypeSubclassWithFinalizer_spec | -
Modules/_testcapimodule.c | - | HeapCTypeWithDict_spec | -
Modules/_testcapimodule.c | - | HeapCTypeWithNegativeDict_spec | -
Modules/_testcapimodule.c | - | HeapCTypeWithWeakref_spec | -
Modules/_testcapimodule.c | - | HeapCTypeSetattr_spec | -
Modules/_testcapimodule.c | - | capsule_name | -
Modules/_testcapimodule.c | - | capsule_pointer | -
Modules/_testcapimodule.c | - | capsule_context | -
Modules/_testcapimodule.c | - | x | -
Modules/_testcapimodule.c | getargs_keyword_only | keywords | -
Modules/_testcapimodule.c | getargs_keywords | keywords | -
Modules/_testcapimodule.c | getargs_positional_only_and_keywords | keywords | -
Modules/_testcapimodule.c | make_exception_with_doc | kwlist | -
Modules/_testcapimodule.c | test_empty_argparse | kwlist | -
Modules/_testcapimodule.c | test_structmembers_new | keywords | -
Modules/_testcapimodule.c | - | ml | -
Modules/_testcapimodule.c | - | TestMethods | -
Modules/_testcapimodule.c | - | generic_alias_methods | -
Modules/_testcapimodule.c | - | generic_methods | -
Modules/_testcapimodule.c | - | meth_instance_methods | -
Modules/_testcapimodule.c | - | meth_class_methods | -
Modules/_testcapimodule.c | - | meth_static_methods | -
Modules/_testcapimodule.c | - | test_members | -
Modules/_testcapimodule.c | - | heapctype_members | -
Modules/_testcapimodule.c | - | heapctypesubclass_members | -
Modules/_testcapimodule.c | - | heapctypewithdict_members | -
Modules/_testcapimodule.c | - | heapctypewithnegativedict_members | -
Modules/_testcapimodule.c | - | heapctypewithweakref_members | -
Modules/_testcapimodule.c | - | heapctypesetattr_members | -
Modules/_testcapimodule.c | - | ContainerNoGC_members | -
Modules/_testcapimodule.c | - | matmulType_as_number | -
Modules/_testcapimodule.c | - | ipowType_as_number | -
Modules/_testcapimodule.c | - | awaitType_as_async | -
Modules/_testcapimodule.c | - | heapctypewithdict_getsetlist | -
Modules/_testcapimodule.c | - | HeapDocCType_slots | -
Modules/_testcapimodule.c | - | HeapGcCType_slots | -
Modules/_testcapimodule.c | - | HeapCType_slots | -
Modules/_testcapimodule.c | - | HeapCTypeSubclass_slots | -
Modules/_testcapimodule.c | - | HeapCTypeWithBuffer_slots | -
Modules/_testcapimodule.c | - | HeapCTypeSubclassWithFinalizer_slots | -
Modules/_testcapimodule.c | - | HeapCTypeWithDict_slots | -
Modules/_testcapimodule.c | - | HeapCTypeWithNegativeDict_slots | -
Modules/_testcapimodule.c | - | HeapCTypeWithWeakref_slots | -
Modules/_testcapimodule.c | - | HeapCTypeSetattr_slots | -
Modules/_testimportmultiple.c | - | _foomodule | -
Modules/_testimportmultiple.c | - | _barmodule | -
Modules/_testimportmultiple.c | - | _testimportmultiple | -
Modules/_testinternalcapi.c | - | _testcapimodule | -
Modules/_testinternalcapi.c | - | TestMethods | -
Modules/_testmultiphase.c | - | slots_create_nonmodule | -
Modules/_testmultiphase.c | - | def_nonmodule | -
Modules/_testmultiphase.c | - | main_def | -
Modules/_testmultiphase.c | - | def_nonmodule_with_methods | -
Modules/_testmultiphase.c | - | def_nonascii_latin | -
Modules/_testmultiphase.c | - | def_nonascii_kana | -
Modules/_testmultiphase.c | - | null_slots_def | -
Modules/_testmultiphase.c | - | def_bad_large | -
Modules/_testmultiphase.c | - | def_bad_negative | -
Modules/_testmultiphase.c | - | def_create_int_with_state | -
Modules/_testmultiphase.c | - | def_negative_size | -
Modules/_testmultiphase.c | - | uninitialized_def | -
Modules/_testmultiphase.c | - | def_create_null | -
Modules/_testmultiphase.c | - | def_create_raise | -
Modules/_testmultiphase.c | - | def_create_unreported_exception | -
Modules/_testmultiphase.c | - | def_nonmodule_with_exec_slots | -
Modules/_testmultiphase.c | - | def_exec_err | -
Modules/_testmultiphase.c | - | def_exec_raise | -
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

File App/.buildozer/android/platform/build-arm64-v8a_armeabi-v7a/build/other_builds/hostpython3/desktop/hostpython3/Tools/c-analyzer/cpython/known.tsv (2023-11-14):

filename | funcname | name | kind | declaration
#filename | funcname | name | kind | is_supported | declaration
#??? | - | PyWideStringList | typedef | ???

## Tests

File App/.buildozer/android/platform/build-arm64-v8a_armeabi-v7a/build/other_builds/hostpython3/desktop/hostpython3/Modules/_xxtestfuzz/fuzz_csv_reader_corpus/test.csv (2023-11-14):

header 1,header 2,header 3,"quoted header", trailing commas,,,,
item, item, 23, xyz, {+}
"1","(abc@example.com)",.,

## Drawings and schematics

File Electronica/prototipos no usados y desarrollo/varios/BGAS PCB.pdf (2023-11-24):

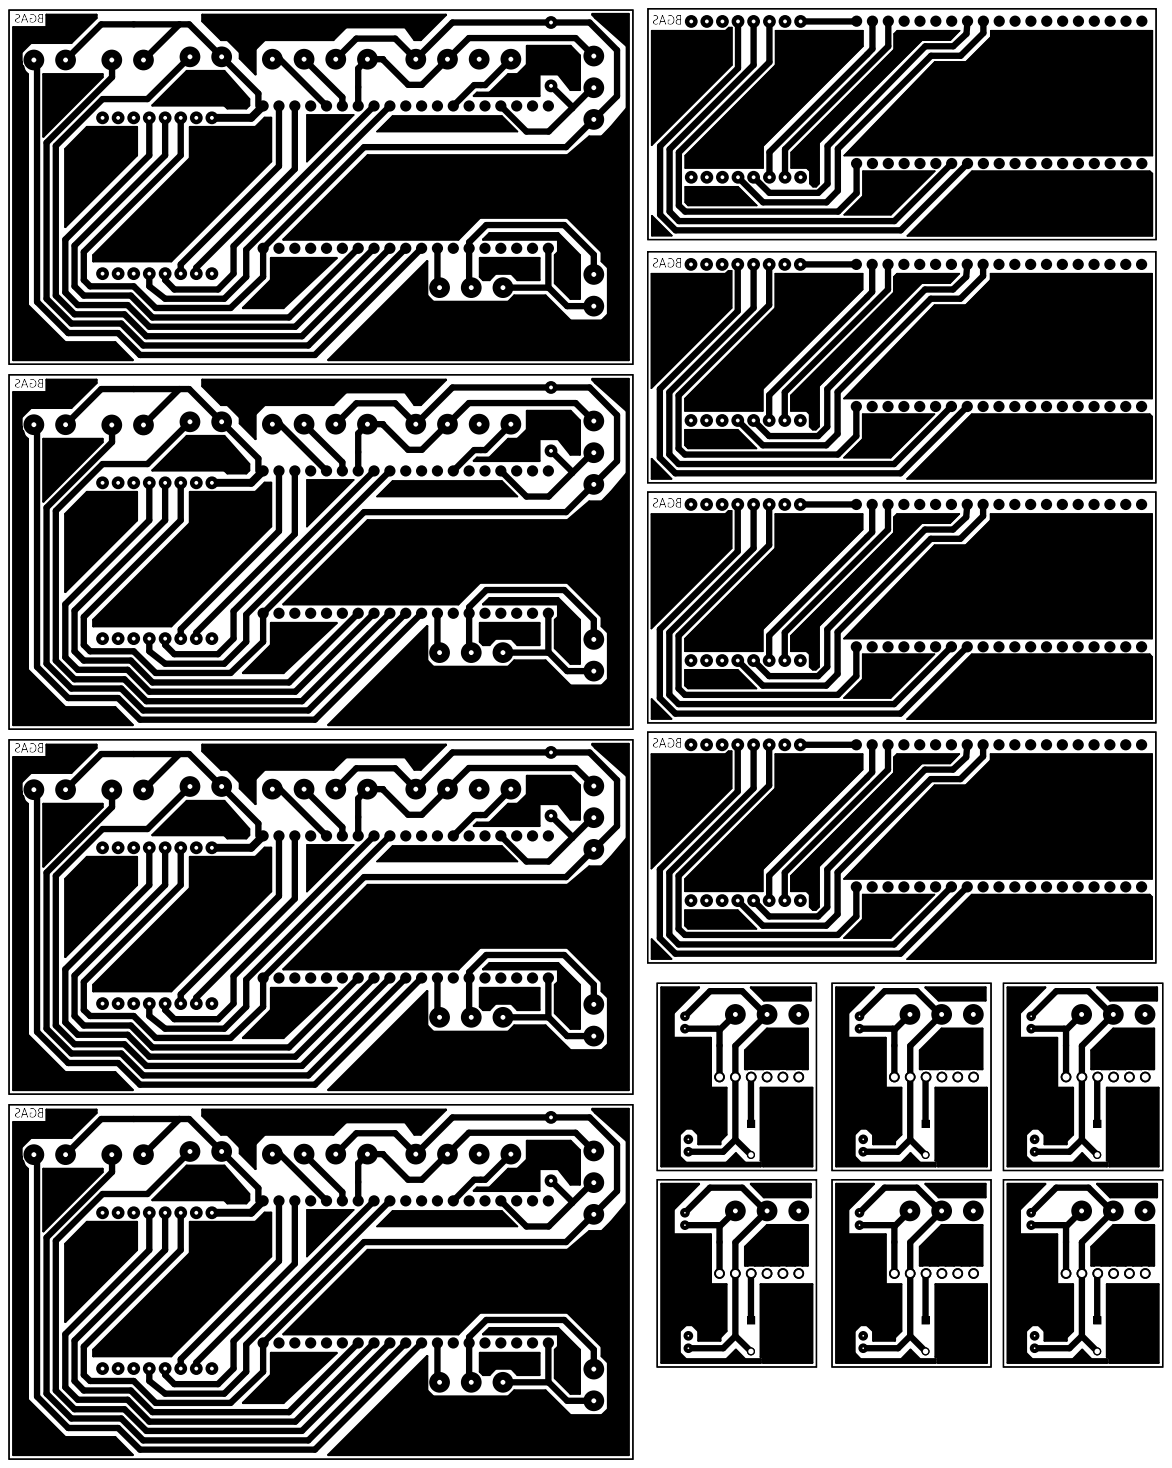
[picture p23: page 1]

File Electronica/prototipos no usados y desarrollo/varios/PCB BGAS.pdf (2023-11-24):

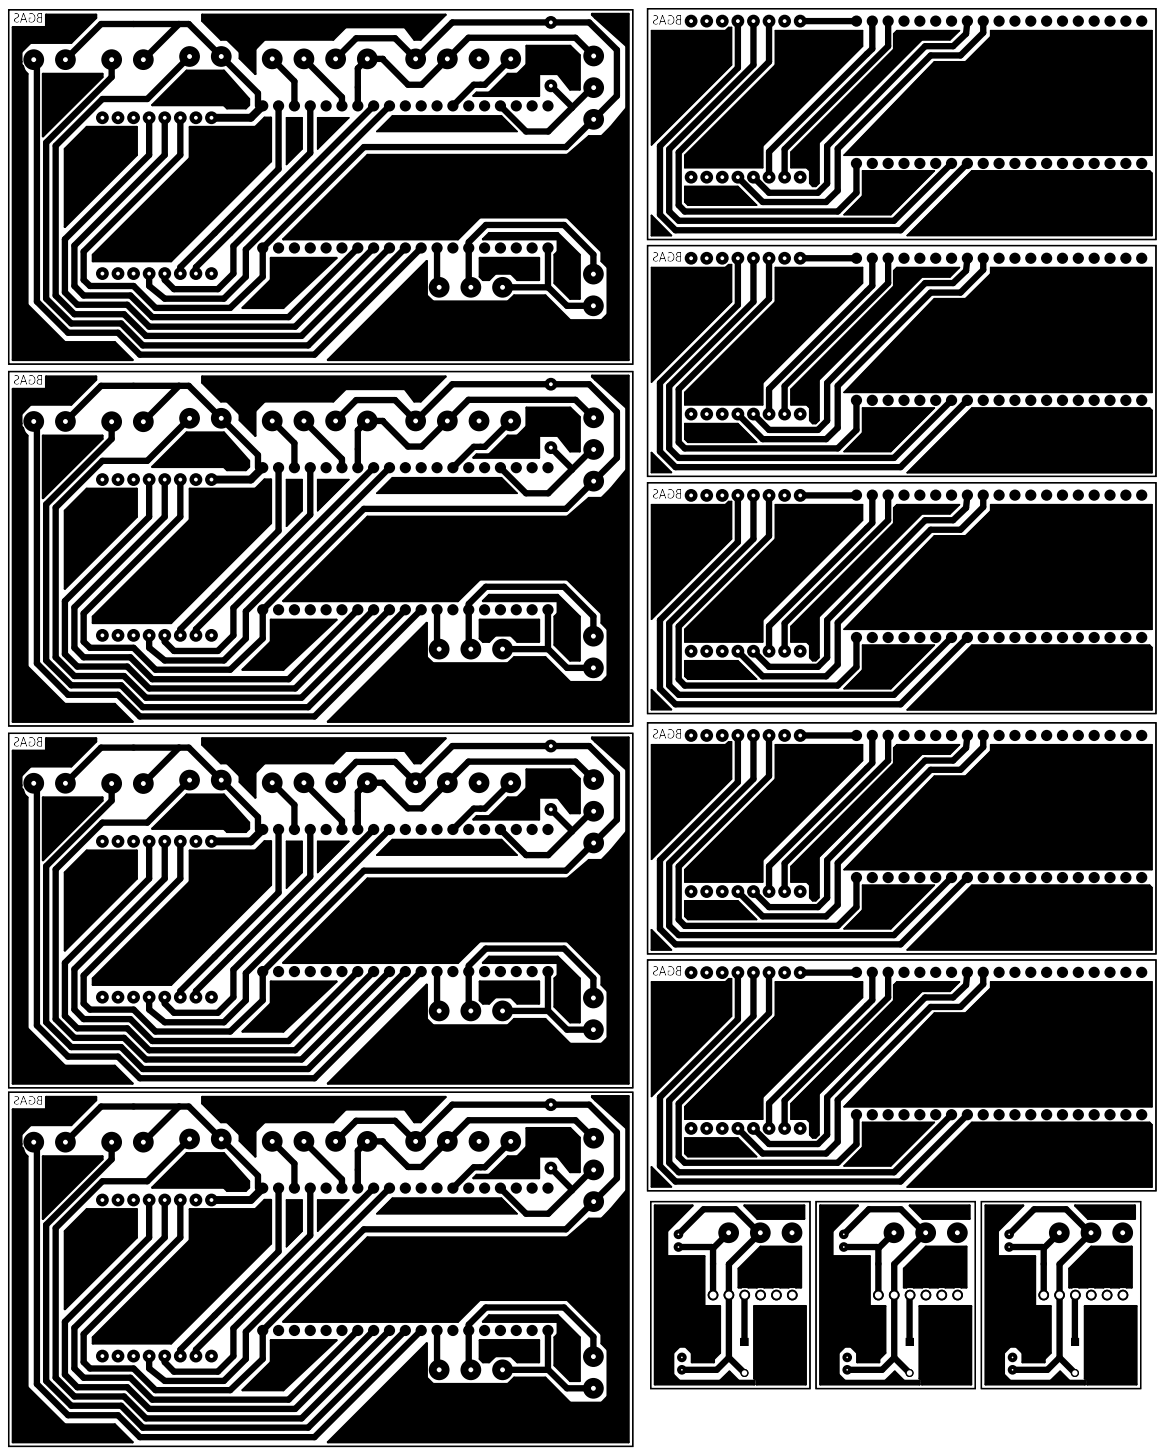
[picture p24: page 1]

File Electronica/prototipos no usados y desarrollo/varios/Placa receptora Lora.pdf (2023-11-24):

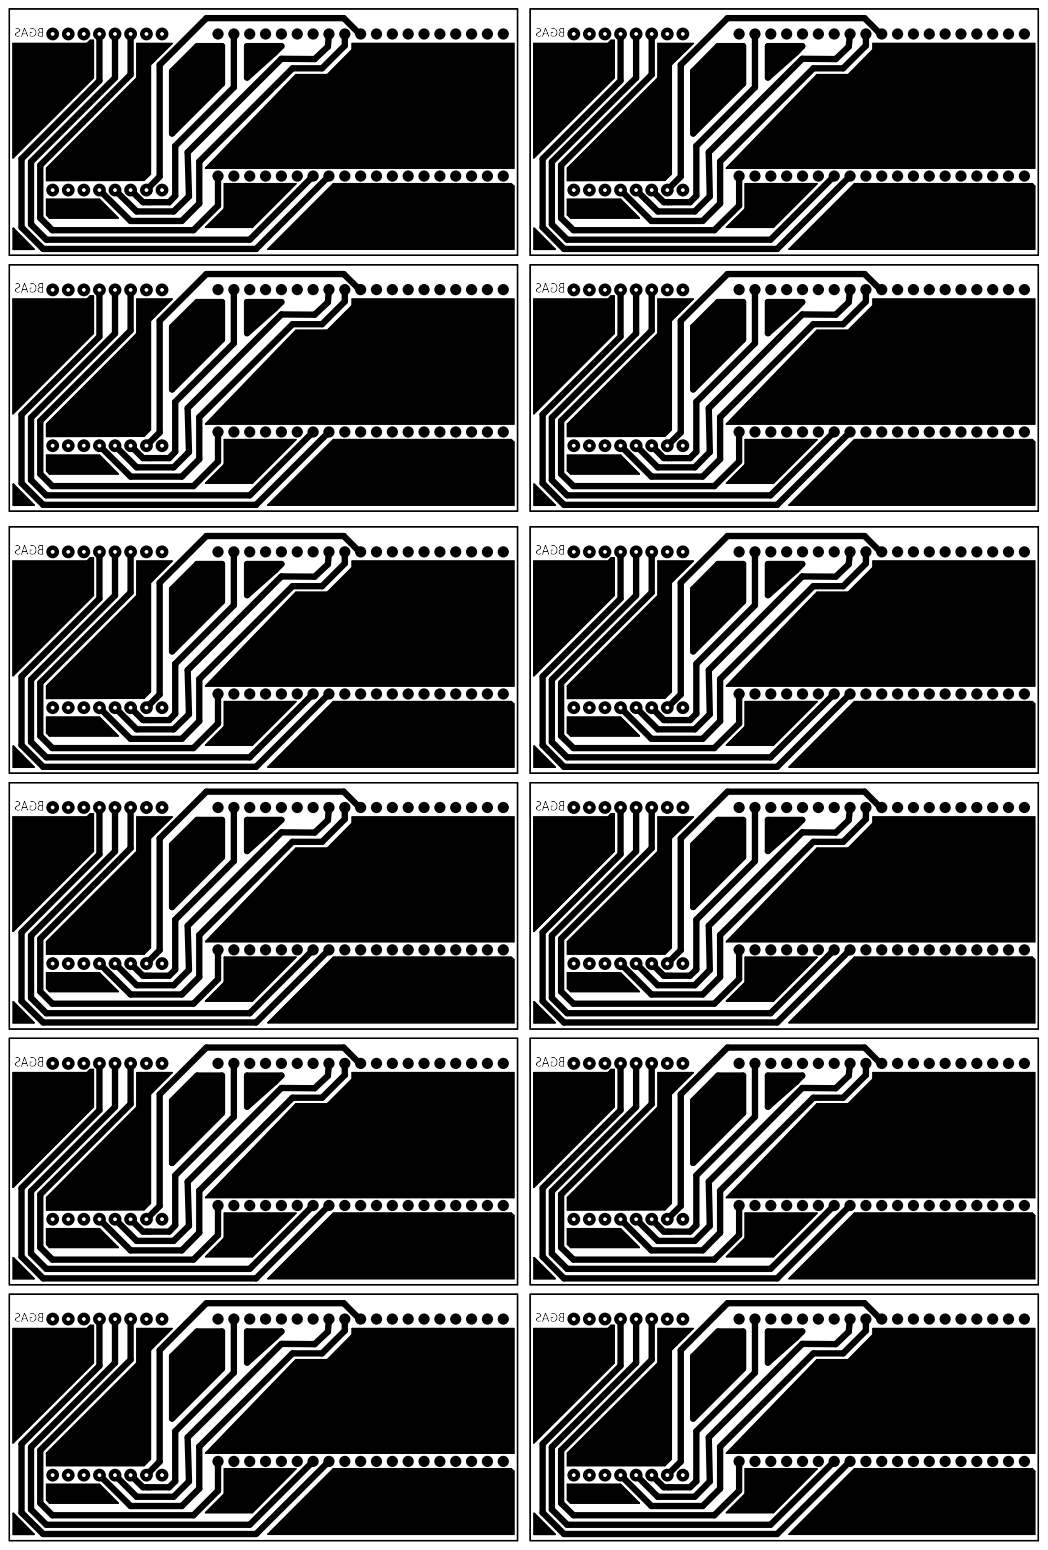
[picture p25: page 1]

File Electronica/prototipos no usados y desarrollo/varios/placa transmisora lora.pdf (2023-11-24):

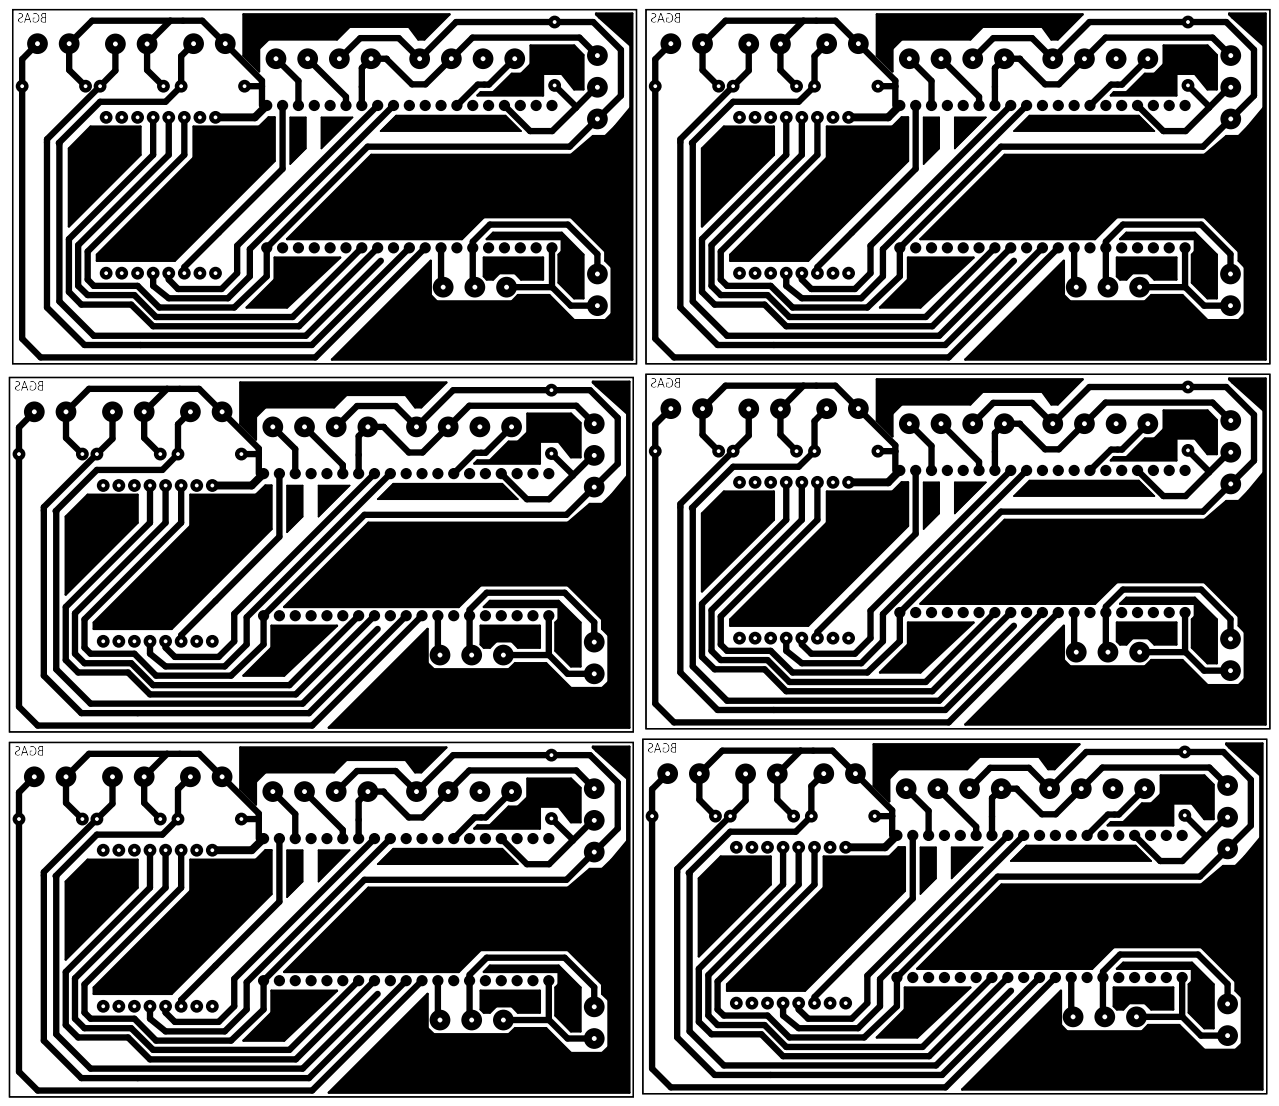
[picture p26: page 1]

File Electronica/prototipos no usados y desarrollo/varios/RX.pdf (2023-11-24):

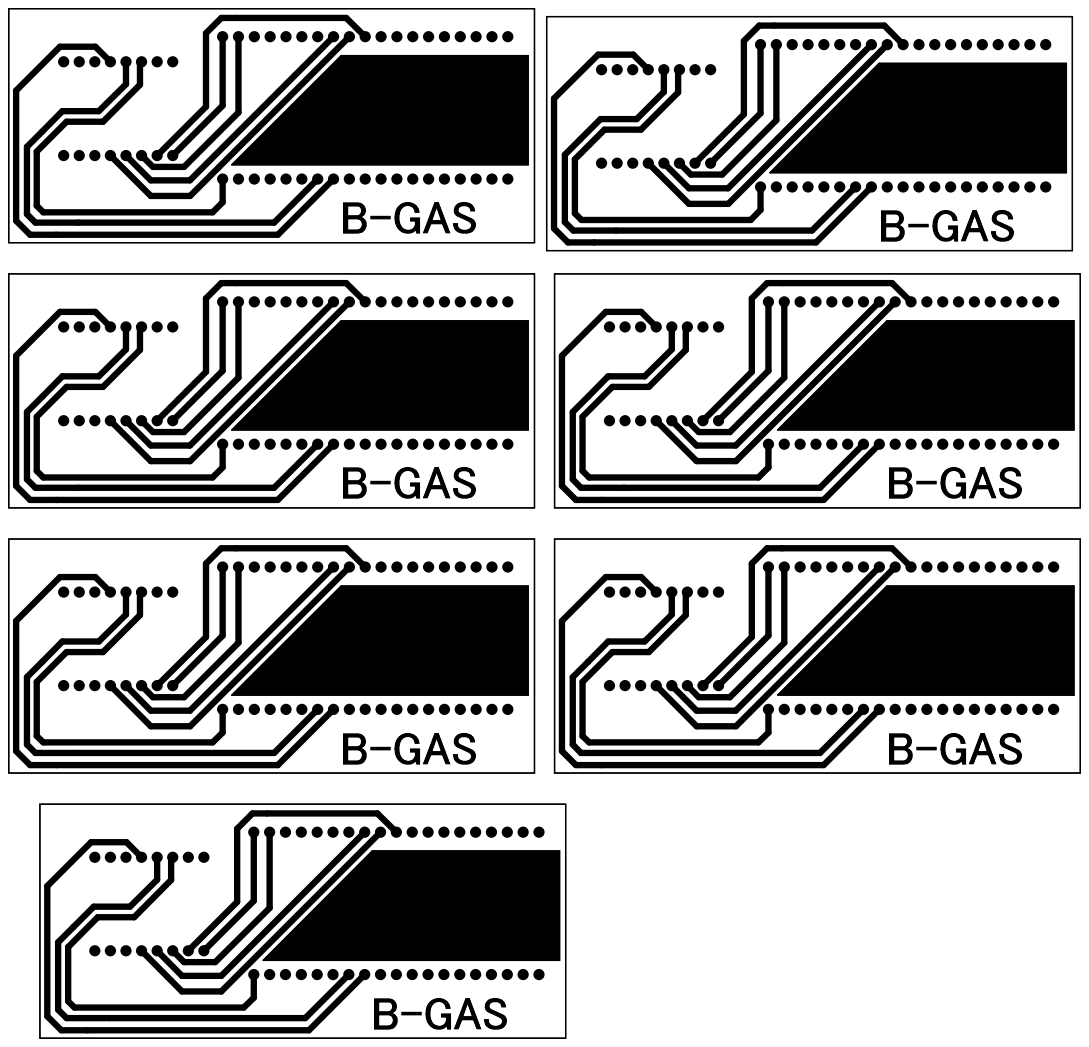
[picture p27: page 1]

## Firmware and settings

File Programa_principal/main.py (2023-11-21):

import pyRTOS
from machine import ADC, Pin, I2C, SoftI2C
from lcd_api import LcdApi
from i2c_lcd import I2cLcd
from time import sleep
import onewire, ds18x20
import utime
from MQ2 import MQ2

button_on_pin = Pin(27, Pin.IN)
button_slide_pin = Pin(26, Pin.IN)
button_time_pin = Pin(25, Pin.IN)
on = 0
slide = 0
button_on = 0
button_slide = 0
birth = 0
tiempo_diasU = 0
tiempo_diasV = 0

# Configurar el pin del sensor de presión MPX5999D
pin_adc = Pin(14)
adc = ADC(pin_adc)
adc.atten(ADC.ATTN_11DB)
max_pressure = 1000.0  # Presión máxima en kPa
adc_resolution = 4096  # Resolución del ADC

#config para MQ2 YEAHHH
pin = Pin(4)
sensor = MQ2(pinData = pin, baseVoltage = 5)

# I2C LCD Configuration
I2C_ADDR = 0x27
totalRows = 2
totalColumns = 16
i2c = SoftI2C(scl=Pin(22), sda=Pin(21), freq=10000)
lcd = I2cLcd(i2c, I2C_ADDR, totalRows, totalColumns)

# DS18X20 Temperature Sensor Configuration
ds_pin = Pin(15)
ds_sensor = ds18x20.DS18X20(onewire.OneWire(ds_pin))
roms = ds_sensor.scan()
print(roms)

#calibrar MQ2
#sensor.calibrate()
#print("Base resistance:{0}".format(sensor._ro))

def task_on(self):
    while True:
        global on
        global button_on
        if button_on == 1:
            if on == 0:
                on = 1
                button_on = 0
            else:
                on = 0
                button_on = 0
        yield [pyRTOS.timeout(0.001)]

def task_slide(self):
    while True:
        global button_slide
        global slide
        global on
        global tiempo_diasU, tiempo_diasV
        global sensor

        if slide == 0 and on == 1:
            adc_value = adc.read()
            adc_value1 = adc_value - 58
            pressure = (adc_value1 / adc_resolution) * max_pressure
            lcd.move_to(0, 0)
            lcd.putstr("Presion:")
            lcd.move_to(0, 1)
            lcd.putstr("{:.2f} kPa".format(pressure))
            print(pressure)
                
            if button_slide == 1:
                slide = 1
                button_slide = 0
                lcd.clear()
                utime.sleep(1)


        elif slide == 1 and on == 1:
            try:
                ds_sensor.convert_temp()
                temperature = ds_sensor.read_temp(roms[0])
                lcd.move_to(0, 0)
                lcd.putstr("Temperatura:")
                lcd.move_to(0, 1)
                lcd.putstr("{:.2f} C".format(temperature))
                print(temperatura)
            except:
                lcd.move_to(0, 0)
                lcd.putstr("Temperatura:")
                lcd.move_to(0, 1)
                lcd.putstr("no disponible")
            
            if button_slide == 1:
                slide = 2
                button_slide = 0
                lcd.clear()
                utime.sleep(1)

        elif slide == 2 and on == 1:
            if birth > 0:
                global tiempo_diasU
                if tiempo_diasU > 0:
                    lcd.move_to(0, 0)
                    lcd.putstr("Eficiente en:")
                    lcd.move_to(0, 1)
                    lcd.putstr(f"{tiempo_diasU} dias")
                elif tiempo_diasV > 0:
                    lcd.move_to(0, 0)
                    lcd.putstr("Eficiente, vence")
                    lcd.move_to(0, 1)
                    lcd.putstr(f"en: {tiempo_diasV} dias")
                else:
                    print(tiempo_diasU, tiempo_diasV)
                    lcd.move_to(0, 0)
                    lcd.putstr("Gen. iniciado")
                    lcd.move_to(0, 1)
                    lcd.putstr(f"hace: {tiempo_diasU} dias")
            else:
                lcd.move_to(0, 0)
                lcd.putstr("Generador no")
                lcd.move_to(0, 1)
                lcd.putstr("iniciado")
                
            if button_slide == 1:
                slide = 0
                button_slide = 0
                lcd.clear()
                utime.sleep(1)
        else:
            lcd.clear()
            """
        elif slide == 2 and on == 1:
            try:
                lcd.move_to(0, 0)
                lcd.putstr("Metano:")
                lcd.move_to(0, 1)
                metano = sensor.readSmoke()
                lcd.putstr("{:.2f} ppm".format(metano))
            except:
                lcd.move_to(0, 0)
                lcd.putstr("Metano:")
                lcd.move_to(0, 1)
                lcd.putstr("no disponible")
            
            if button_slide == 1:
                slide = 3
                button_slide = 0
                utime.sleep(1)
"""
        yield [pyRTOS.timeout(0.1)]

def task_button_on(self):
    while True:
        global button_on, button_on_pin
        if button_on_pin.value() == True:
            button_on = 1
            lcd.clear()
            utime.sleep(1)
        yield [pyRTOS.timeout(0.01)]


def task_button_slide(self):
    while True:
        global button_slide
        if button_slide_pin.value() == True:
            button_slide = 1
        yield [pyRTOS.timeout(0.01)]

def task_button_time(self):
    while True:
        global birth
        if button_time_pin.value() == True:
            birth = utime.time()
        yield [pyRTOS.timeout(0.01)]

def task_time(self):
    while True:
        global birth
        global tiempo_diasU
        global tiempo_diasV
        if birth == True:
            tiempo_actual = utime.time()
            
            tiempo_transcurrido = tiempo_actual - birth
            tiempo_sec = int(tiempo_transcurrido)
            tiempo_finU = 1209600 - tiempo_sec
            tiempo_diasU = int(tiempo_finU // 86400)
            tiempo_transcurrido = tiempo_actual - birth
            tiempo_finV = 7776000 - tiempo_sec
            tiempo_diasV = int(tiempo_finV // 86400)
        yield [pyRTOS.timeout(1)]

pyRTOS.add_task(pyRTOS.Task(task_on, name="task_on", mailbox=True))
pyRTOS.add_task(pyRTOS.Task(task_slide, name="task_slide", mailbox=True))
pyRTOS.add_task(pyRTOS.Task(task_time, name="task_time", mailbox=True))
pyRTOS.add_task(pyRTOS.Task(task_button_on, name="task_button_on", mailbox=True))
pyRTOS.add_task(pyRTOS.Task(task_button_slide, name="task_button_slide", mailbox=True))
pyRTOS.add_task(pyRTOS.Task(task_button_time, name="task_button_time", mailbox=True))

pyRTOS.start()

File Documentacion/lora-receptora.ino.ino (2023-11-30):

#include <SPI.h>
#include <LoRa.h>

#define NSS 15
#define RST 22
#define DIO0 36

void setup() {
  Serial.begin(115200);
  Serial.println("LoRa Sensor Receiver");

  delay(500);

  LoRa.setPins(NSS, RST, DIO0);

  if (!LoRa.begin(868E6)) {
    Serial.println("Starting LoRa failed!");
    while (1);
  }

  LoRa.receive();
}

void loop() {
  int packetSize = LoRa.parsePacket();
  if (packetSize) {
    // Lee el paquete recibido
    String receivedData = "";
    while (LoRa.available()) {
      receivedData += (char)LoRa.read();
    }

    // Muestra los valores en el puerto serie
    Serial.println("Received data: " + receivedData);
  }
}

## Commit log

2023-09-04 Update and rename Index.html to index.html
    Habilitar "index.html" como tal, para que pueda ser abierto desde este repositorio
2023-09-04 Cambios de las rutas de acceso, corregidas
2023-09-04 Update index.html
    Cambio de una mayuscula
2023-09-04 Update contacto.html
    Cambio de una i (letra minuscula) a una I(letra mayuscula) en el href de INFORMACIÓN
2023-09-04 Reducción de los archivos ".html" para pasar de tener una p+agina ramificada, a tener una más extensa. (Hacer más grande el "index")
2023-09-04 Remoción de "contacto.httml" y "Información.html"
2023-09-04 Refrenciación de los puntos clables dentro del código
2023-09-04 Correción de estructura html
2023-09-04 Inclusión de la división entre sections
2023-09-04 Coreeción de código
2023-09-05 Cambio en la justificación del contenido de la nav bar
2023-09-05 coreción margin de la navbar
2023-09-05 cambio de loading.js a loading.txt
2023-10-25 Update index.html
    Expansión y cambio por completo de la estructura HTML
2023-10-25 Update index.html
    eliminación de comentarios innecesarios
2023-10-25 Update estilos.css
    ReWork de todos los estilos de la página
2023-10-25 Update index.html
    eliminación de código innecesario
2023-10-26 Update index.html
    Correciones de ortografias en los textos de las ecciones "Electónica" y "Diseño"
2023-11-02 Update index.html
    fav.ico de la página cambiado del de webflos al de bgas
2023-11-02 Update index.html
    Eliminación de los signos de exclamación "!¡" en la sección de "Contacto"
2023-11-10 Update index.html
    corección en la tarjeta de presentación de Chioli Lautaro
2023-11-14 Aplicacion subida, totalmente funcional
    [datos.csv, ignored.tsv, known.tsv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]
2023-11-17 change to index.html
    Elimine signos de exclamación del "gracias por visitarnos"
2023-11-18 Organizacion adecuada de los archivos de la pagina Web
2023-11-18 "Files tree" incluido
    A recomendación de Medina, a mejorar en el futuro cercano
2023-11-21 directorio de programa principal
2023-11-21 cambiado link de ig
2023-11-21 imagenes de estructura
    Estas imagenes fueron tomadas durante el proceso de crear la estructura.
2023-11-22 link a web de bgas
2023-11-23 Balde hermético 3D
    [HERMETIC.blend]
2023-11-23 Caja para impresión 3D del LoRa receptor
    [Case_Reciver.blend]
2023-11-23 Caja para impresión 3D del LoRa transmisor
    [Case_Transmisor.blend]
2023-11-23 subido doc de fracasos
2023-11-24 web anda de vuelta (fea)
2023-11-24 Imagen demostrativa, motor de renderizado Cycles
2023-11-24 Modelo 3D de la estructura texturizada
2023-11-24 Modelo 3D, Estructura usada para distribución
    [BGASPRO.blend]
2023-11-24 Demostración del modelo para distribución
    Modelo pensado para uso del consumidor en caso de posible uso empresarial.
2023-11-24 Modelo 3D del 1st diseño estructural
    [OldBGAS.blend]
2023-11-24 Create WEB
    Carpeta donde estan destinados a estar los archivos relacionados a a la web de BGas
2023-11-24 BGAS para distribución por detrás
2023-11-24 Imagen demostrativa de la caja receptora
2023-11-24 Imagen demostrativa de la caja transmisora
2023-11-24 Update README.md
    Se agrego informacion de funcionamiento y biogas
2023-11-24 Render de modelo sin texturizar
2023-11-24 Video 360 de la estructura
2023-11-24 Caja del Receptor lista para impresión 3D
    [Reciver_Print.stl]
2023-11-24 Tapa de la caja del Transmisor para impresión 3D
    [Transmisor_TOP_Printer.stl]
2023-11-24 Caja del Transmisor para impresión 3D
    [Transmisor_BOT_Print.stl]

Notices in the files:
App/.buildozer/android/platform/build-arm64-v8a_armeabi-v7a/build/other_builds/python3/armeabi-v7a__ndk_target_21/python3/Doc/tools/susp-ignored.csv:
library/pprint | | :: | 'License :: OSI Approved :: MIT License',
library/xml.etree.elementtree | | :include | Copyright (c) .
